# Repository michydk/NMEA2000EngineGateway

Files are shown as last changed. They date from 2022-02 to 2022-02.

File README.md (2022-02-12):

# NMEA2000EngineGateway

Basicly an non invasive way to messure oil and coolingwater temperature along with RPM on altenator, and then report result via NMEA 2000 to plotter.

Based on the shoulders of my hero's, including but not limited to:

DallasTemperature: Miles Burton https://github.com/milesburton

NMEA2000: Timo Lappalainen https://github.com/ttlappalainen

OneWire: Paul Stoffregen https://github.com/PaulStoffregen

More info can be found on my blog https://sillydiy.blogspot.com/2022/01/measuring-boat-engine-temperature-wih.html

# PCB
PCB production: https://aisler.net/p/SUMPWCYW 
Schems etc. is included in the "Arduino_RPM_Shield" folder

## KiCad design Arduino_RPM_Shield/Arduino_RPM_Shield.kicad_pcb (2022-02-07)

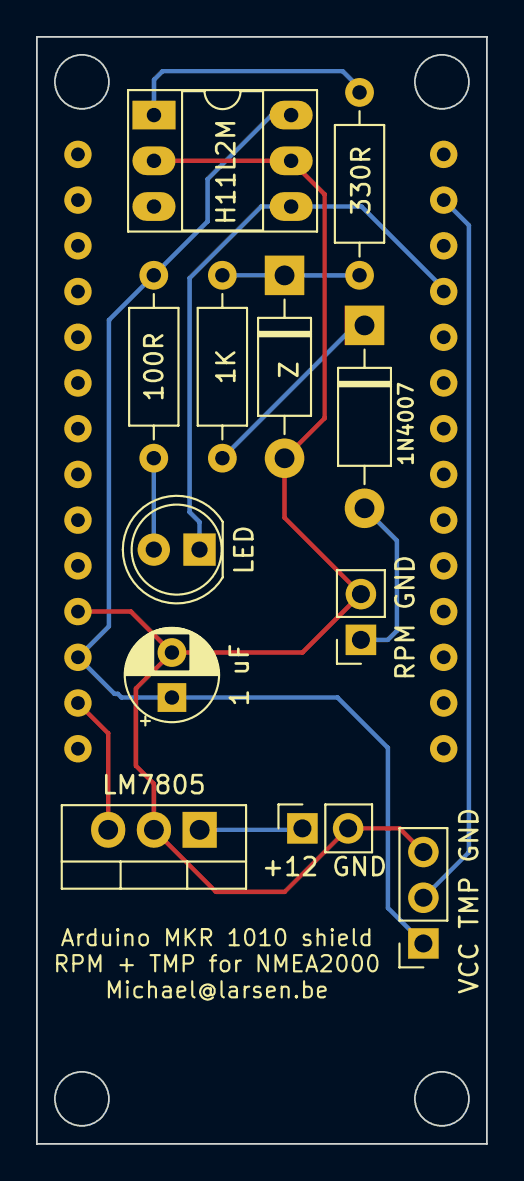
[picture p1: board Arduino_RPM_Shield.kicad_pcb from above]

Board: 2 copper layers, 25.0 x 61.5 mm, 13 parts (0 on the bottom side), 11 nets.

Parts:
C1: 1 uF; CP_Radial_D5.0mm_P2.50mm
D1: 1N4007; D_DO-41_SOD81_P10.16mm_Horizontal
D2: 1N4732A; D_DO-41_SOD81_P10.16mm_Horizontal
D3: LED; LED_D5.0mm
J1: RPM GND; PinSocket_1x02_P2.54mm_Vertical
J3: +12 GND; PinSocket_1x02_P2.54mm_Vertical
J4: VCC TMP GND; PinSocket_1x03_P2.54mm_Vertical
MKR1: Arduino_MKR_Shield; Arduino_MKR
R1: 1K; R_Axial_DIN0207_L6.3mm_D2.5mm_P10.16mm_Horizontal
R2: 330R; R_Axial_DIN0207_L6.3mm_D2.5mm_P10.16mm_Horizontal
R3: 100R; R_Axial_DIN0207_L6.3mm_D2.5mm_P10.16mm_Horizontal
U1: H11L2M; DIP-6_W7.62mm_Socket_LongPads
U2: LM7805; TO-220-3_Vertical

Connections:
+12V: J3.1, U2.1 (VI)
GND: C1.2, D2.2 (A), J1.2, J3.2, J4.3, MKR1.25 (GND), U1.2, U1.5, U2.2 (GND)
unnamed: C1.1, J4.1, MKR1.26 (3V3), R3.1, U1.6
unnamed: D1.1 (K), R1.1
unnamed: D2.1 (K), R1.2, R2.1
unnamed: D3.1 (K), MKR1.11 (D2), U1.4
unnamed: D3.2 (A), R3.2
unnamed: J4.2, MKR1.13 (D4)
unnamed: MKR1.27 (Vin), U2.3 (VO)
unnamed: R2.2, U1.1
Tacho IN: D1.2 (A), J1.1

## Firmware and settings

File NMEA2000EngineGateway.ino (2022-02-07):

// Send DIY temp readings to NMEA 2000 bus.
// Based on the shoulders of my heros, Including but not limited to:
// DallasTemperature: Miles Burton https://github.com/milesburton
// NMEA2000: Timo Lappalainen https://github.com/ttlappalainen
// OneWire: Paul Stoffregen https://github.com/PaulStoffregen

#include <Arduino.h>
#define USE_N2K_CAN 1
#define N2k_SPI_CS_PIN 3
#define N2k_CAN_INT_PIN 7
#define USE_MCP_CAN_CLOCK_SET 16
#include <NMEA2000_CAN.h>  
#include <N2kMessages.h>
#include <OneWire.h>
#include <DallasTemperature.h>

// List here messages your device will transmit.
const unsigned long TransmitMessages[] PROGMEM={127489L,0};
#define ONE_WIRE_BUS 4 // Data wire is plugged into pin 4 on the Arduino
#define ALARMPIN 6 // Alarm pin to interface to buzzer, LED etc.
#define DEBUG
#define TempUpdatePeriod 2000
#define RPMUpdatePeriod 500
#define PERIOD_US 100L
#define OilAlarmTemp 85
#define CoolingAlarmTemp 85
#define CrankPulleyDiameter 127.86
#define AlternatorPulleyDiameter 58
#define PairsOfPoles 6
bool MotorAlarm = false;
const byte RPMPin=2;

//int intaketemp = 0;
int ratio = CrankPulleyDiameter / AlternatorPulleyDiameter;
int PulsePerRev = PairsOfPoles * ratio;
int coolingtemp = 0;int oiltemp = 0;
int pulses = 0, lastPulses = 0 ;
long eventTime = 0L, lastEventTime = 0L, prev_time =0L ; bool lastInput =0; 
OneWire oneWire(ONE_WIRE_BUS);
DallasTemperature sensors(&oneWire);

// Assign the addresses of your 1-Wire temp sensors.
DeviceAddress cooling = {0x28, 0xFF, 0xCB, 0x30, 0x81, 0x15, 0x03, 0x6A };
DeviceAddress oil = {0x28, 0xFF, 0x9D, 0x67, 0x81, 0x15, 0x03, 0x3D };
//DeviceAddress intake = {0x28, 0xFF, 0xBB, 0x31, 0x81, 0x15, 0x03, 0x88 }; // Not really used, as there is no PNG for intake temp

void setup() {
  // Set Product information    
  NMEA2000.SetProductInformation("01", // Manufacturer's Model serial code
                                 100, // Manufacturer's product code
                                 "SillyDIY Engine Temp monitor",  // Manufacturer's Model ID
                                 "1.0.0.3 (2022-01-24)",  // Manufacturer's Software version code
                                 "1.0.0.3 (2022-01-24)" // Manufacturer's Model version                              
                                 );
  // Set device information
  NMEA2000.SetDeviceInformation(112233, // Unique number. Use e.g. Serial number.
                                160, // Device function=Temperature. See codes on http://www.nmea.org/Assets/20120726%20nmea%202000%20class%20&%20function%20codes%20v%202.00.pdf
                                50, // Device class=Sensor Communication Interface. See codes on  http://www.nmea.org/Assets/20120726%20nmea%202000%20class%20&%20function%20codes%20v%202.00.pdf
                                174 // Just choosen free from code list on http://www.nmea.org/Assets/20121020%20nmea%202000%20registration%20list.pdf                               
                               );                             
  #ifdef DEBUG
    Serial.begin(115200);
    //NMEA2000.SetForwardStream(&Serial);
    //NMEA2000.SetForwardType(tNMEA2000::fwdt_Text); 
  #endif
  
  NMEA2000.SetMode(tNMEA2000::N2km_NodeOnly,22); // If you also want to see all traffic on the bus use N2km_ListenAndNode instead of N2km_NodeOnly below
  NMEA2000.EnableForward(false); 
  NMEA2000.ExtendTransmitMessages(TransmitMessages);
  NMEA2000.Open();
  pinMode(RPMPin, INPUT);
  prev_time += PERIOD_US ;
}

void loop() {
   #ifdef DEBUG
       //Serial.print("----------------- ");Serial.print(millis()); Serial.println(" -----------------");
       //discoverOneWireDevices(); // Enable this to see your Temp sensor addresses 
   #endif
 
  //sensors.requestTemperatures();
  SendN2kData();
  NMEA2000.ParseMessages();
}

void SendN2kData() {
  static unsigned long TempUpdated=millis();
  static unsigned long RPMUpdated=millis();
  tN2kMsg N2kMsg;
// TEMP
  if ( TempUpdated+TempUpdatePeriod<millis() ) {
    TempUpdated=millis();
    ReadSensors();
    #ifdef DEBUG
      Serial.print("Cooling temp ");Serial.println(coolingtemp); 
      Serial.print("Oil temp ");Serial.println(oiltemp);
    #endif

    NMEA2000.SendMsg(N2kMsg);

    // Sending PGN 127489  
    if (coolingtemp > OilAlarmTemp || coolingtemp > CoolingAlarmTemp ) {
      SetN2kEngineDynamicParam(N2kMsg, 0, N2kDoubleNA, ReadoilTemp(), ReadEngineTemp(), N2kDoubleNA, N2kDoubleNA, N2kDoubleNA, N2kInt8NA,N2kInt8NA, N2kInt8NA, N2kInt8NA, false, true);
    } 
    else {
      SetN2kEngineDynamicParam(N2kMsg, 0, N2kDoubleNA, ReadoilTemp(), ReadEngineTemp(), N2kDoubleNA, N2kDoubleNA, N2kDoubleNA, N2kInt8NA,N2kInt8NA, N2kInt8NA, N2kInt8NA, false, false);
    }
    NMEA2000.SendMsg(N2kMsg);
  }
// RPM
  if ( RPMUpdated+RPMUpdatePeriod<millis() ) {
    RPMUpdated=millis();
    bool thisInput = digitalRead (RPMPin) ;
    if (lastInput != thisInput)   // account for every transition
      {
        account_pulses () ;
        lastInput = thisInput ;
      }
    if (micros() - prev_time >= PERIOD_US)  // regularly report
      {
      int puls1= ((pulses - lastPulses) * 6e7 / (eventTime - lastEventTime)) ;
      double rpm = puls1 / PulsePerRev; // totally wrong, but hay, am just testing..
      
      // PulsePerRev
      SetN2kPGN127488(N2kMsg, 0,  rpm, N2kDoubleNA, N2kInt8NA);
      #ifdef DEBUG
        Serial.print("Pulses ");
        Serial.println(pulses);
        Serial.print("Rpm ");
        Serial.println(rpm);
      #endif
      prev_time += PERIOD_US ;
      NMEA2000.SendMsg(N2kMsg);

/*
 * The crank pulley diameter is 127.86mm
The alternator pulley diameter is 58mm
Ration of 2.2044 to 1
12 pole alternator, 6 pairs of poles
Pulses per rev= number of pairs of poles x the pulley ratio.
6 x 2.2044 = 13.23 pulse per rev, for reference the standard number of pulses per rev for the original alternator is 10.29
This convert to frequencies of:
220 Hz at 1,000 rpm; 440 HZ at 2,000rpm and 660Hz at 3000 rpm
*/    
      }
  }
}
void account_pulses ()
{
  pulses ++ ;
  eventTime = micros() ;
}

void ReadSensors() {
 sensors.requestTemperatures();
 oiltemp = (sensorValue(oil)); 
 coolingtemp = (sensorValue(cooling));
 // intaketemp = (sensorValue(intake));
 // The value -127.00 is basicly unconnected.
 if (oiltemp == -127.00) { oiltemp = 0;} if (coolingtemp == -127.00) { coolingtemp = 0;} 
 //if (intaketemp == -127.00) { intaketemp = 0;}
}

float sensorValue (byte deviceAddress[])
{
  float tempC = sensors.getTempC (deviceAddress);
      #ifdef DEBUG
        //Serial.print("Sensorvalue: : "); 
        //Serial.println(tempC); 
    #endif
  return tempC;
}

double ReadoilTemp() {
  return CToKelvin(oiltemp); // Read here the true temperature e.g. from analog input
}

double ReadEngineTemp() {
  return CToKelvin(coolingtemp); // Read here the true temperature e.g. from analog input
}


void discoverOneWireDevices(void) {
  byte i;
  byte present = 0;
  byte data[12];
  byte addr[8];
  
  Serial.print("Looking for 1-Wire devices...\n\r");
  while(oneWire.search(addr)) {
    Serial.print("\n\rFound \'1-Wire\' device with address:\n\r");
    for( i = 0; i < 8; i++) {
      Serial.print("0x");
      if (addr[i] < 16) {
        Serial.print('0');
      }
      Serial.print(addr[i], HEX);
      if (i < 7) {
        Serial.print(", ");
      }
    }
    if ( OneWire::crc8( addr, 7) != addr[7]) {
        Serial.print("CRC is not valid!\n");
        return;
    }
  }
  Serial.print("\n\r\n\rThat's it.\r\n");
  oneWire.reset_search();
  return;
}

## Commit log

2022-02-07 Init PCB ver 1.0
    [Arduino_RPM_Shield.kicad_pcb, Arduino_RPM_Shield.kicad_sch]
2022-02-07 Update README.md
    Added link for PCB production
